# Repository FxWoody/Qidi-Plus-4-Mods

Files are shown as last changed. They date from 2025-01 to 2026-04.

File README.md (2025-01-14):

# Qidi Plus 4
Mods, Prints and config files for the QP4 of my own machine
The config files here are working 100% on my printer, i cannot garantee, nor be responsible, if the setups in here will be fully working on yours if you have not install or modified them.
Every modifications have been taken from Qidi-Community page as for what was available.
Some of my OWN mods are minor readjustments i made to my printer according to the reference of Community.

PLEASE make sure you have fully made a back-up of your system before using these config :)

Enjoy !!!

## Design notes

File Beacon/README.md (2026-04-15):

# **BEACON RevH "Normal" INSTALL ON QIDI PLUS 4**

## ***---IMPORTANT---***
## These MACRO SCRIPT FILES are from my own QIDI PLUS 4 modifications in order to make Beacon3D probe to work and is mainly, a copy of Stew675's AMAZING script.
##

### :+1:Please be advise that these modifications are not PART of QIDI's own Klipper and therefor, i will not take any responsability for any issues that could prevail from using these scripts. I have also made many more adjusments that have been taken from the community page and that are fully integrated into these, thanks to crew of Discord, and that you can read here : [Qidi-Community](https://github.com/qidi-community/Plus4-Wiki/tree/main). :+1:

#### *** This install is fully working and should be followed very carefully :wink:*** ####

## Install the PROBE on the toolhead
Download my files from Printables:
https://www.printables.com/model/1165232-qidi-plus-4-beacon-cooling-fan

Or you can use Stew's setup :
https://www.printables.com/model/1170120-beacon3d-mount-for-qidi-plus4

> ***NOTE that by using my Beacon Module installation, the probe will be on the right side on the tool head and requires to replace the cooling DUCT !!! I have added the STL for this puposes and my fan/duct system is more efficient than the original one***
> blower-beacon

Remove old probe, fan housing, and replace with new printed one.
**I will make some DEMO pic soon**

## Let's get ready in the KLIPPER :

In order to install Beacon, you will need to SSH into MKS folder with Mobaxterm 

Follow this to SSH how to: [SSH Communtity](https://github.com/qidi-community/Plus4-Wiki/blob/main/content/ssh-access/README.md).

Once in SSH, you will need to install the Beacon script:
> ***Install Beacon Module***
#### Clone beacon_klipper from git and run the install script:

```
cd ~
git clone https://github.com/beacon3d/beacon_klipper.git
./beacon_klipper/install.sh
```

Now that **BEACON** is installed, we need to replace the ***PROBE.PY*** inside the **KLIPPER**.
Navigate to the ***/home/mks/klipper/klippy/extras/*** like so : 

https://github.com/user-attachments/assets/80a6965c-9cf2-4efb-97a6-fbfab288c99c
#### From here, we have two choice in order to replace the Python File ####
You can simply **DRAG & DROP** the file you recovered earlier from your PC, or double click the PROBE.PY, this will open the **MobaTextEditor** ,select ALL, and paste the PROBE.PY file over-write it. 
> [!NOTE]
> Saving will bring you to a contextual menu for you to agree to **SAVE**.
After this, we are done in SSH mode.

## Copy/Paste of the .cfg files
> [!IMPORTANT]
***First -***, in your QP4 configuration, locate the **printer.cfg** and **gcode_macro.cfg**, rename those as ***park-printer.cfg*** and ***park-gcode_macro.cfg*** so that you can revert to it later (saving it on your PC with notepad or your favorite editor, *Mobaxterm* as is own that you can use, is even better as a backup)
>
> ***NOTE -*** My config files have been tuned for my OWN printer and might need to be readjusted to your printer setup. I have removed the mods that are not necessary, but, i would HIGLY suggest that you install SHAKETUNE :
> https://github.com/qidi-community/ShakeTune-For-Plus4

Open the ***printer.cfg & gcode_macro.cfg*** from this repository and copy them into each of your ***Configuration Files*** by creating each new files like so :

***NOTE THAT I OMIT THE ".CFG" AFTER WRITING "PRINTER" ...PLEASE REMEMBER TO ADD IT WHEN CREATING YOUR FILE*** 

https://github.com/user-attachments/assets/59b034cf-4111-4476-8d64-ce53f5c2da31
> [!IMPORTANT]
Then, simply COPY / PASTE each macro into their own folder .... **Save & Restart** will be ask at each file closer. I have also include KAMP settings if you want to adjust it to your taste (but it is set for quick purging  **NOTE:** ***LINE_PURGE need to be added to your printer setings Machine_start-gcode***)
>
> Now that Beacon is install, we are ready to do the **calibrations**.
>
## Calibration of your new Beacon
With all the above changes in place (and the firmware restarted) your Beacon can now be easily calibrated with the following typed into the Gcode Console:
```
G32
G29
G31
SAVE_CONFIG
```
This will set the Plus4 to generate a default bed mesh (G32), then do a full calibration home and bed mesh (G29), and then finally put the Plus4 back into Kamp mode meshing ready for the next print (G31). The whole lot gets saved afterwards (SAVE_CONFIG)

>
> Please refer to the "Beacon Instal Page" in the link below for proper calibration and better understanding of the probe.

# Links to External

SSH software: [MobaXterm](https://mobaxterm.mobatek.net/download.html).

Beacon Install page: [Beacon](https://docs.beacon3d.com/quickstart/).

Beacon Probe RevH: [Beacon Probe RevH Model : Normal](https://beacon3d.com/product/beacon-h/).

Qidi Community Work : [Qidi-Community Github](https://github.com/qidi-community/Plus4-Wiki/tree/main).

Facebook QidiTech : [QidiTech Officia](https://www.facebook.com/groups/qiditechofficialusers).



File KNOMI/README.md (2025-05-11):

# **KNOMI V1 INSTALL ON QIDI PLUS 4**

## ***---IMPORTANT---***
## These MACRO SCRIPT FILES are from my own QIDI PLUS 4 modifications in order to make KNOMI to work.
##

### :+1:Please be advise that these modifications are not PART of QIDI's own Klipper and therefor, i will not take any responsability for any issues that could prevail from using these scripts. I have also made many more adjusments that have been taken from the community page and that are fully integrated into these, thanks to crew of Discord, and that you can read here : [Qidi-Community](https://github.com/qidi-community/Plus4-Wiki/tree/main). :+1:

#### *** This install is fully working and should be followed very carefully. Do not forget that this MOD is based on the BEACON mod and is fully implemented for it but should FIT without it too except for some differences on the cover built :wink:*** ####

## Install the KNOMI in the toolhead cover
Download my files from Printables:

Knomi Cover: [Fxwoody Printables](https://www.printables.com/model/1214824-qidi-plus-4-knomi-cover)

## Let's get ready in the CONFIGS :

In order to have KNOMI to hook with our printer, we need to UPDATE the firmware first.

Follow the instructions from BTT page

BTT Knomi: https://bttwiki.com/KNOMI.html

## Add Knomi.cfg to your repo

>In printer.cfg, add the macro link
> `[include KNOMI.cfg]`

>[!IMPORTANT]
>#### Use the PB4 connector to power your Knomi

> Find :
```ruby
[heater_fan hotend_fan2]
pin:PB4
max_power: 1.0
shutdown_speed:1.0
kick_start_time: 0.5
heater: extruder
heater_temp: 50.0
fan_speed: 1.0
off_below: 0
```

and replace with:

```ruby
[output_pin knomi]
pin: PB4
value: 1
shutdown_value: 1
```
pcb

## Create your KNOMI.cfg file and paste this in it
```ruby
[gcode_macro _KNOMI_STATUS]
variable_homing: False
variable_probing: False
variable_qgling: False
variable_heating_nozzle: False
variable_heating_bed: False
gcode:

[gcode_macro M109]
rename_existing: M109.1
gcode:
  SET_GCODE_VARIABLE MACRO=_KNOMI_STATUS VARIABLE=heating_nozzle VALUE=True
  M109.1 {rawparams}
  SET_GCODE_VARIABLE MACRO=_KNOMI_STATUS VARIABLE=heating_nozzle VALUE=False

[gcode_macro M190]
rename_existing: M190.1
gcode:
  SET_GCODE_VARIABLE MACRO=_KNOMI_STATUS VARIABLE=heating_bed VALUE=True
  M190.1 {rawparams}
  SET_GCODE_VARIABLE MACRO=_KNOMI_STATUS VARIABLE=heating_bed VALUE=False

[gcode_macro G28]
rename_existing: G28.1
gcode:
  SET_GCODE_VARIABLE MACRO=_KNOMI_STATUS VARIABLE=homing VALUE=True
  G28.1 {rawparams}
  SET_GCODE_VARIABLE MACRO=_KNOMI_STATUS VARIABLE=homing VALUE=False

[gcode_macro _BED_MESH_CALIBRATE]
rename_existing: BTT_BED_MESH_CALIBRATE
gcode:
  SET_GCODE_VARIABLE MACRO=_KNOMI_STATUS VARIABLE=qgling VALUE=True
  BTT_BED_MESH_CALIBRATE {rawparams}
  SET_GCODE_VARIABLE MACRO=_KNOMI_STATUS VARIABLE=qgling VALUE=False

[gcode_macro Z_TILT_ADJUST]
rename_existing: BTT_Z_TILT_ADJUST
gcode:
 SET_GCODE_VARIABLE MACRO=_KNOMI_STATUS VARIABLE=probing VALUE=True
 BTT_Z_TILT_ADJUST
 SET_GCODE_VARIABLE MACRO=_KNOMI_STATUS VARIABLE=probing VALUE=False
```

# Links to External

VS Code software: [Visual Studio Code](https://code.visualstudio.com/).

KNOMI V1: [KNOMI](https://bttwiki.com/KNOMI.html).

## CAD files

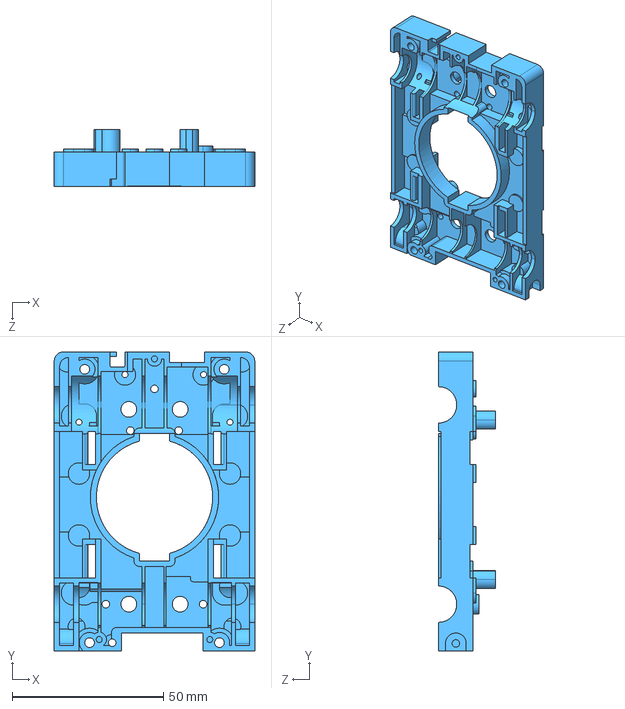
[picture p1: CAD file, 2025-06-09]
QidiP4/plus4底座后.STEP
66.4 x 99.0 x 18.8 mm

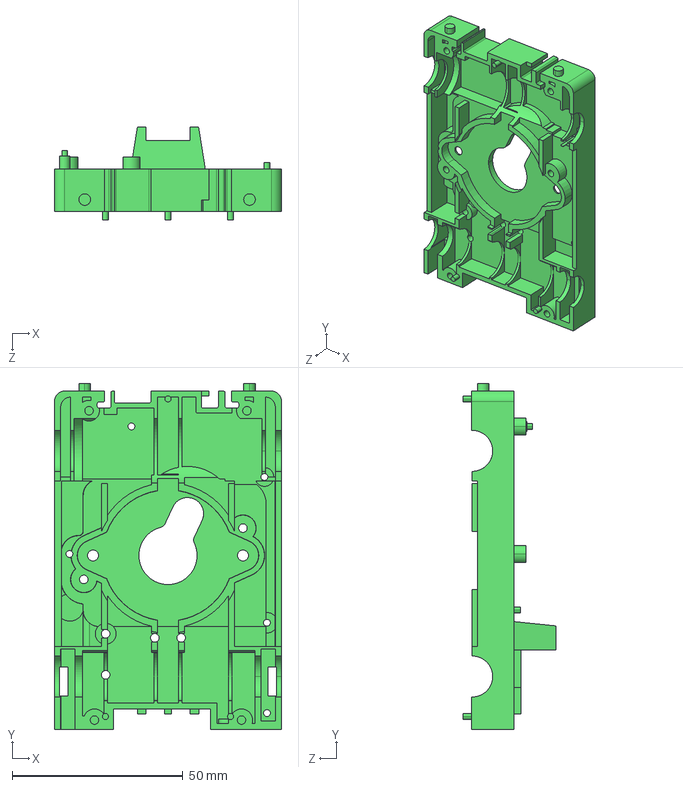
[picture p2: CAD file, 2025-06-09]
QidiP4/plus4底座前.STEP
66.4 x 101.2 x 27.2 mm

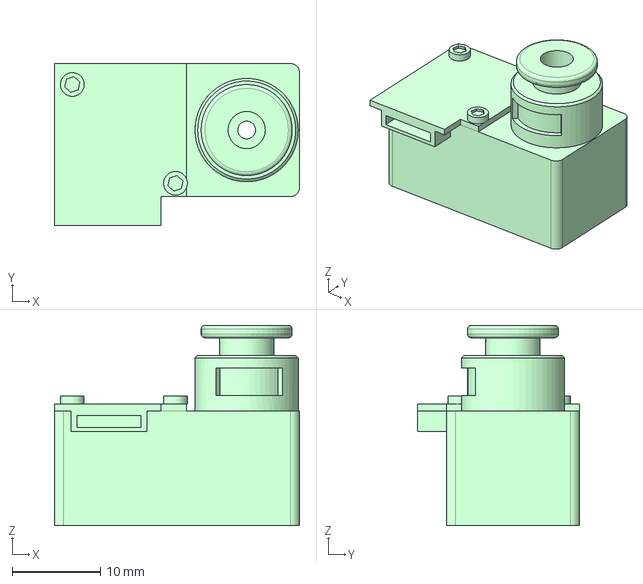
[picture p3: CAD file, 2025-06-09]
QidiP4/filament-sensor.stp
27.8 x 18.4 x 22.7 mm

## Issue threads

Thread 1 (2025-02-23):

cartographer compatibility

naytmare1, 2025-02-23:
Would this mount also work with cartographer v3 standard?

naytmare1, 2025-02-23:
i really like the design, I tried printing this with ASA but its always to brittle I dont know if my ASA has a problem hopefully I can think of a different orientation so

Closed 2025-02-23.

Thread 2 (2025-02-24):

Which Beacon H variation?

JohnnyPicnic, 2025-02-24:
Hi, could you include in your documentation with variation you are using or if it matters?
Normal or Low Profile.
Thanks!

FxWoody, 2025-02-24:
I add it but if you look at the links at the bottom i did specified it 😁👍

JohnnyPicnic, 2025-02-24:
Yup I see it now 😆 thanks.

FxWoody, 2025-02-24:
I will redo the whole install this week as i am using a mix of Stew675 and my scripts instead. Much better and i will upload both files here to simply copy-paste them with every modifications done and adjusted inside your machines.

Closed 2025-02-24.

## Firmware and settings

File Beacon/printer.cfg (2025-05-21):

# QIDI Plus4 V1.0.0

[include plr.cfg]
[include gcode_macro.cfg]
[include time_update.cfg]

# Plugins
[include timelapse.cfg]
[include KAMP_Settings.cfg]
#[include KNOMI.cfg]

[mcu]
serial: /dev/ttyS2
restart_method: command
baud:500000

[mcu U_1]
serial: /dev/ttyS0
restart_method: command
baud:500000

[temperature_sensor GD32]
sensor_type: temperature_mcu
sensor_mcu: mcu

[temperature_sensor mainboard_stm32]
sensor_type: temperature_mcu
sensor_mcu: U_1

[temperature_sensor mainboard_rockchip]
sensor_type: temperature_host

[respond]
default_type: echo

[save_variables] 
filename =/home/mks/printer_data/config/saved_variables.cfg

[resonance_tester]
accel_per_hz: 150
max_smoothing:0.5

[duplicate_pin_override]
pins:

[bed_screws]
screw1:15,15
screw1_name: Front left
screw2: 290,15
screw2_name: Front right
screw3: 285,290
screw3_name: Last right
screw4: 28,290

[screws_tilt_adjust]
screw1:5,20
screw1_name: Front left
screw2: 260,20
screw2_name: Front right
screw3: 260,280
screw3_name: Back right
screw4: 5,280
screw4_name: Back left
screw_thread: CW-M4

[hall_filament_width_sensor]
adc1: PA2
adc2: PA3
cal_dia1: 1.50
cal_dia2: 2.0
raw_dia1: 14397
raw_dia2: 15058
default_nominal_filament_diameter: 1.75
max_difference: 0
measurement_delay: 50
enable: false
measurement_interval: 10
logging: False
min_diameter: 0.3
use_current_dia_while_delay: False
pause_on_runout:True
runout_gcode:
            RESET_FILAMENT_WIDTH_SENSOR
            M118 Filament run out
event_delay: 3.0
pause_delay: 0.5

[extruder]
step_pin:PB9
dir_pin:PB8
enable_pin:!PC15
rotation_distance: 54.130 #53.7 22.6789511 Bondtech 5mm Drive Gears
gear_ratio: 1517:170
microsteps: 64 #16
full_steps_per_rotation: 200 #200 for 1.8 degree, 400 for 0.9 degree
nozzle_diameter: 0.400
filament_diameter: 1.75
min_temp: 0
max_temp: 380
min_extrude_temp: 175
smooth_time: 0.000001
heater_pin:PB3
sensor_type:MAX6675
sensor_pin:PB12
spi_speed: 100000
spi_software_sclk_pin:PB13
spi_software_mosi_pin:PA11
spi_software_miso_pin:PB14
max_power: 1

#control : pid  
#pid_Kp=33.555
#pid_Ki=4.76
#pid_Kd=59.141

pressure_advance: 0.032
pressure_advance_smooth_time: 0.03
max_extrude_cross_section: 500
instantaneous_corner_velocity: 10.000
max_extrude_only_distance: 1000.0
max_extrude_only_velocity:5000
max_extrude_only_accel:5000
step_pulse_duration:0.000002

[tmc2209 extruder]
uart_pin:PC13
interpolate: False #True
run_current: 0.8 #0.714
stealthchop_threshold: 0

[adxl345]
cs_pin:PA4
spi_software_sclk_pin:PA5
spi_software_mosi_pin:PA7
spi_software_miso_pin:PA6
axes_map: -x, z, -y

[printer]
kinematics:corexy
max_velocity: 600
max_accel: 20000
max_accel_to_decel: 10000
max_z_velocity: 20
max_z_accel: 500
square_corner_velocity: 5

[stepper_x]
step_pin:U_1:PB4
dir_pin:!U_1:PB3
enable_pin:!U_1:PB5
microsteps:32
rotation_distance: 38.86
full_steps_per_rotation:200 # set to 400 for 0.9 degree stepper
endstop_pin:tmc2240_stepper_x:virtual_endstop
position_min: -1.5
position_endstop: -1.5
position_max:307
homing_speed:75 #50
homing_retract_dist:0
homing_positive_dir:false
step_pulse_duration:0.0000001

[stepper_y]
step_pin:U_1:PC14
dir_pin:!U_1:PC13
enable_pin:!U_1:PC15
microsteps: 32
rotation_distance: 38.86
full_steps_per_rotation:200 # set to 400 for 0.9 degree stepper
endstop_pin:tmc2240_stepper_y:virtual_endstop
position_min: -2
position_endstop: -2
position_max:325
homing_speed:75 #50
homing_retract_dist:0
homing_positive_dir:false
step_pulse_duration:0.0000001

[stepper_z]
step_pin:U_1:PB1
dir_pin:U_1:PB6
enable_pin:!U_1:PB0
microsteps:16 #128
rotation_distance: 4
full_steps_per_rotation: 200
endstop_pin:probe:z_virtual_endstop # U_1:PC3 for Z-max
endstop_pin_reverse:tmc2209_stepper_z:virtual_endstop
#position_endstop:1
position_endstop_reverse:285
position_max:285
position_min: -4
homing_speed: 15
homing_speed_reverse: 15#10
second_homing_speed: 35
homing_retract_dist: 0 #5.0
homing_positive_dir:false
homing_positive_dir_reverse:true
#step_pulse_duration:0.0000001

[stepper_z1]
step_pin:U_1:PC10
dir_pin:U_1:PA15
enable_pin:!U_1:PC11
microsteps:16 #128
rotation_distance: 4
full_steps_per_rotation: 200
endstop_pin_reverse:tmc2209_stepper_z1:virtual_endstop
#step_pulse_duration:0.0000001

[z_tilt]
z_positions:
    -17.5,152
    335.7,152

points:
    40,152
    260,152

speed: 200
horizontal_move_z: 15
retries: 2
retry_tolerance: 0.015

[tmc2240 stepper_y]
cs_pin:U_1:PB9
spi_software_sclk_pin:U_1:PA5
spi_software_mosi_pin:U_1:PA7
spi_software_miso_pin:U_1:PA6
spi_speed:200000
run_current: 1.15
#hold_current: 0.5
interpolate: False #true
stealthchop_threshold:0
diag0_pin:!U_1:PC0
driver_SGT:1

[tmc2240 stepper_x]
cs_pin:U_1:PD2
spi_software_sclk_pin:U_1:PA5
spi_software_mosi_pin:U_1:PA7
spi_software_miso_pin:U_1:PA6
spi_speed:200000
run_current: 1.15
# hold_current: 0.5
interpolate:False #true
stealthchop_threshold:0
diag0_pin:!U_1:PB8
driver_SGT:1

[tmc2209 stepper_z]
uart_pin:U_1: PB7
run_current: 1.15
# hold_current: 0.17
interpolate: False #True
stealthchop_threshold: 999999
diag_pin:^U_1:PA13
driver_SGTHRS:100

[tmc2209 stepper_z1]
uart_pin:U_1: PC5
run_current: 1.15
# hold_current: 0.17
interpolate: False #True
stealthchop_threshold: 999999
diag_pin:^U_1:PC12
driver_SGTHRS:100

[heater_bed]
heater_pin: U_1:PB10
sensor_type:NTC 100K MGB18-104F39050L32
sensor_pin:U_1: PA0
max_power: 1.0
control = pid
pid_Kp=63.418 
pid_Ki=1.342 
pid_Kd=749.125
pwm_cycle_time:0.001
min_temp: -60
max_temp: 125

[temperature_sensor chamber_probe]
sensor_type:NTC 100K MGB18-104F39050L32
sensor_pin:U_1:PA1

[heater_generic chamber]
heater_pin:U_1:PC8
max_power:0.6 #0.4
pwm_cycle_time:0.02088            # Reduced to 0.02088 seconds to reduce flicker (within 0.3 limit)
control = pid
pid_Kp=45
pid_Ki=0.1
pid_Kd=5000
#control = pid
#pid_Kp=63.418 
#pid_Ki=1.342 
#pid_Kd=749.125
min_temp:-100
max_temp:80#70
target_min_temp:40
#target_max_temp:65
sensor_type: temperature_combined
sensor_list: temperature_sensor GD32, temperature_sensor chamber_probe, temperature_sensor GD32, temperature_sensor GD32
combination_method: mean
maximum_deviation: 70
heat_with_heater_bed:True
heat_with_heater_bed_tem_add:25

[verify_heater chamber]
max_error: 300
check_gain_time:1200 #480
hysteresis: 5
heating_gain: 1

[temperature_sensor Chamber_Thermal_Protection_Sensor]
sensor_type:NTC 100K MGB18-104F39050L32
sensor_pin:U_1:PC2
min_temp:-100
max_temp:130

[verify_heater extruder]
max_error: 120
check_gain_time:20
hysteresis: 5
heating_gain: 1

[verify_heater heater_bed]
max_error: 200
check_gain_time:360
hysteresis: 10
heating_gain: 1

[fan_generic exhaust_fan]
pin: U_1:PA8
shutdown_speed: 0.0
cycle_time: 0.0100
hardware_pwm: false
kick_start_time: 0.100
off_below: 0.0

[fan_generic chamber_circulation_fan]
pin: U_1:PC9
shutdown_speed: 0.0
cycle_time: 0.0100
hardware_pwm: false
kick_start_time: 0.100
off_below: 0.0

[chamber_fan chamber_fan]
pin:U_1:PA4
max_power: 1.0
shutdown_speed: 1.0
kick_start_time: 0.5
heater:chamber
fan_speed: 1.0
off_below: 0
idle_timeout:60
idle_speed:1.0

[output_pin knomi]
pin: PB4
value: 1
shutdown_value: 1

[heater_fan hotend_fan]
pin:PB5
max_power: 1.0
shutdown_speed:1.0
kick_start_time: 0.5
heater: extruder
heater_temp: 50.0
fan_speed: 1.0
off_below: 0

[fan_generic Raiser_Cooler]
pin:PB10
max_power: 1.0
shutdown_speed:0.0 #1.0
cycle_time: 0.0100
hardware_pwm: false
kick_start_time: 1.0
off_below: 0

[fan_generic cooling_fan]
pin:PA8
max_power: 1.0
shutdown_speed:0
cycle_time: 0.010
hardware_pwm: False
kick_start_time: 0.100
off_below: 0.0
tachometer_pin:PA9
tachometer_ppr: 2
tachometer_poll_interval: 0.0015

[controller_fan board_fan]
pin:U_1:PB2

[temperature_sensor mainboard_stm32]
sensor_type: temperature_mcu
sensor_mcu: U_1

[temperature_sensor mainboard_rockchip]
sensor_type: temperature_host

[temperature_fan adaptive_board_fan]
pin:U_1:PC4
max_power: 1.0
shutdown_speed: 1.0
cycle_time: 0.01
sensor_type: temperature_combined
sensor_list: temperature_sensor mainboard_stm32, temperature_sensor mainboard_rockchip
combination_method: max                                           # use the maximum reading of the sensors
maximum_deviation: 999.9                                          # we don't care about the difference in temperature
control: pid
pid_deriv_time: 2.0
pid_Kp: 5
pid_Ki: 2
pid_Kd: 5
target_temp: 45
min_speed: 0.8
max_speed: 1.0
min_temp: 0
max_temp: 100

[output_pin caselight]
pin: U_1:PC7
pwm: false
shutdown_value:1
value:1

[output_pin beeper]
pin:U_1: PA2
pwm: false
shutdown_value:0
value:0

[output_pin ctlyd]
pin:U_1: PA14
pwm: false
shutdown_value:0
value:0
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

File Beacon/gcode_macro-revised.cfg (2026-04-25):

# QIDI Plus4 V1.0.0

[gcode_macro _CG28]
gcode:
    {% if "xyz" not in printer.toolhead.homed_axes %}
        G28
    {% endif %}
    
[gcode_macro _APPLY_NOZZLE_OFFSET]
description: Determine the global nozzle offset and apply
variable_hotend_temp: 250               # Target hotend temp (typically set by PRINT_START)
variable_probe_temp_delta: 75           # We probe at this amount less than the hotend temp
variable_reference_position: 5.0        # A safe Z position at which we'll apply the offset change
variable_offset_correction: 0.07        # Static Offset Correction
gcode:
    # Set our local working variables.  We treat everything as floats for these calculations
    {% set reference_position = reference_position|float %}
    {% set offset_correction  = offset_correction|float %}

    # Determine the rest of our working variables
    {% set z_home_x = printer.configfile.settings.beacon.home_xy_position[0] %}
    {% set z_home_y = printer.configfile.settings.beacon.home_xy_position[1] %}
    {% set z_speed  = printer.configfile.settings['stepper_z'].homing_speed|float * 60 %}
    
    {% set target_position = (reference_position + offset_correction)|float %}

    # Report to the console what we've determined
    { action_respond_info("Applying Z offset adjustment for hotend temperature of %.1f°C" % hotend_temp|float) }
    { action_respond_info("  Offset Correction    = %.3f" % (offset_correction)|float) }
    { action_respond_info("  Reference Position   = %.1f" % (reference_position)|float) }
    { action_respond_info("  Target Position      = %.6f" % (target_position)|float) }

    SET_GCODE_OFFSET Z=0                            # Clear any pre-existing Gcode offsets
    G1 Z{target_position} F{z_speed}                # Move Z to determined target position
    G1 X{z_home_x} Y{z_home_y} F7200                # Move X/Y to Z homing position 
    M400                                            # Wait for prior gcode-commands to finish
    SET_KINEMATIC_POSITION Z={reference_position}   # Set target position to be the reference position
    G1 Z{reference_position} F600                   # Move Z to reference position.  Ideally the bed should not move
    M400

[gcode_macro _SETTLE_PRINT_BED]
gcode:
    G1 Z4 F600                              # Move to Z=4
    G91                                     # Enter relative positioning mode
    M400                                    # Wait for all prior commands to finish
    {% for z in range(50) %}                # Loop 50 times
        G1 Z1 F5000                         # Move bed down by 1mm
        G1 Z-1 F5000                        # Move bed up by 1mm
    {% endfor %}
    G90                                     # Go back to absolute positioning mode
    M400                                    # Wait for all prior commands to finish
    G1 Z4 F600                              # Make sure Z=4mm before we leave the macro

[gcode_macro _FIND_Z_EQUALS_ZERO]
gcode:
    {% set hotend_temp = (printer["gcode_macro _APPLY_NOZZLE_OFFSET"].hotend_temp)|float %}
    {% set probe_temp_delta = (printer["gcode_macro _APPLY_NOZZLE_OFFSET"].probe_temp_delta)|float %}

    {% set z_home_temp = hotend_temp - probe_temp_delta %}
    {% set z_home_x = printer.configfile.settings.beacon.home_xy_position[0] %}
    {% set z_home_y = printer.configfile.settings.beacon.home_xy_position[1] %}

    M104 S{z_home_temp}                     # Commence nozzle warmup for z homing        
    BED_MESH_CLEAR                          # Clear out any existing bed meshing context
    SET_KINEMATIC_POSITION Z=0              # Force firmware to believe Z is homed at 0
    G1 Z3 F600                              # Move bed away from the nozzle by 3mm from where it was
    SET_KINEMATIC_POSITION CLEAR=XYZ        # Ensure all kinematic repositionings are cleared
    SET_GCODE_OFFSET Z=0                    # Comnpletely reset all prior notions of Z offset
    G28 X Y                                 # Home X and Y Axes
    {% if (printer.configfile.settings['beacon model default'] is defined) %}
        G28 Z METHOD=proximity              # Do a rapid proximity based Z home if possible
    {% else %}
        M109 S{z_home_temp}                 # Wait for nozzle to fully heat up
        G28 Z METHOD=CONTACT CALIBRATE=0    # Home Z axis without calibration
    {% endif %}
    _SETTLE_PRINT_BED                        # Try to settle the build plate
    M109 S{z_home_temp}                     # Wait for nozzle to fully reach Z probing temperature
    G28 Z METHOD=CONTACT CALIBRATE=1        # Home Z axis, and calibrate beacon                                     
    Z_TILT_ADJUST                           # Ensure bed is level
    G1 X{z_home_x} Y{z_home_y} F7200        # Move to Z home position
    G4 P15000                               # Heatsoak hotend for 15s more
    G28 Z METHOD=CONTACT CALIBRATE=1        # Establish Z=0
    G1 Z3 F600                              # Move bed away from the nozzle by 3mm from where it was
    _APPLY_NOZZLE_OFFSET

[gcode_macro APPLY_FILAMENT_OFFSET]
description: Apply a Z offset adjustment for a specific filament
gcode:
    {% set filament_z = params.Z|default(0)|float %}
    { action_respond_info("Setting Filament Offset to %.3fmm" % (filament_z)) }
    SET_GCODE_OFFSET Z_ADJUST={filament_z}
    
# All the following zoffset calls only exist to keep Qidi's xindi happy
[gcode_macro zoffset]
description: Apply baseline Z offset which is always zero for Beacon Contact
gcode:
    SET_GCODE_OFFSET Z=0                    # Apply a zero gcode_offset

# Development test
[gcode_macro test_zoffset]
description: Debugging test to compare the probe contact and proximity Z Offset values
gcode:
    G28 X Y
    get_zoffset
    M400
    BEACON_OFFSET_COMPARE
    G4 P5000
    G1 Z10 F600

[gcode_macro get_zoffset]
description: Homes nozzle against build plate and applies global z offset
gcode:
    _FIND_Z_EQUALS_ZERO

[gcode_macro save_zoffset]
description: Use APPLY_FILAMENT_OFFSET instead
gcode:
    { action_respond_info("Use APPLY_FILAMENT_OFFSET instead") }

[gcode_macro set_zoffset]
description: Apply baseline Z offset which is always zero for Beacon Contact      
gcode: 
    SET_GCODE_OFFSET Z=0                    # Apply a zero gcode_offset

# Specialized for power lose recovery
[gcode_macro CLEAR_NOZZLE_PLR]
gcode:
    {% set hotendtemp = params.HOTEND|default(250)|int %}
    {% if (printer.gcode_move.position.z ) < 35 %}
        G1 Z35 F900
    {% else %}
        G91
        G1 Z{5} F900 
        G90
    {% endif %}
    G1 X56 F12000
    G1 Y310 F12000
    G1 Y324 F600
    G1 X95 F600
    M400

    M106 S0
    M109 S{hotendtemp}

    G92 E0
    G1 E5 F50
    G92 E0
    G1 E80 F200
    G92 E0
    G1 E-2 F200
    G4 P300

    M106 S255
    G1 Y316 F30000
    G1 Y320 F3000
    G1 Y316 F30000
    G1 Y320 F3000
    G1 Y316 F30000
    G1 Y320 F3000
    G1 Y316 F12000
    G1 Y312 F600

[gcode_macro CLEAR_NOZZLE]
gcode:
    {% set hotendtemp = params.HOTEND|default(250)|int %}
    {% if (printer.gcode_move.position.z ) < 35 %}
        G1 Z35 F900
    {% else %}
        G91
        G1 Z{5} F900 
        G90
    {% endif %}
    G1 X56 F12000
    G1 Y310 F12000
    G1 Y324 F600
    G1 X95 F600
    M400
    M109 S{hotendtemp}
    G92 E0
    G1 E5 F50
    G92 E0
    G1 E80 F200
    G92 E0
    G1 E-2 F200

    M106 S255
    G4 P5000
    M104 S140
    G1 Y318 F9000
    G1 Y322 F600
    G1 Y318 F9000
    G1 Y322 F600
    G1 Y308 F30000
    G1 Y324 F600

    G1 X124 E-1 F1000 

    TEMPERATURE_WAIT SENSOR=extruder MAXIMUM={170}

    G1 X133 F200
    G1 Y321 F200
    G2 I0.5 J0.5 F600
    G2 I0.5 J0.5 F600
    G2 I0.5 J0.5 F600

    G1 Y319 F150
    G1 X132 
    G1 Y324
    G1 X131 
    G1 Y319
    G1 X130
    G1 Y324
    G1 X129
    G1 Y319

    G1 X113 F200
    G1 Y320
    G1 X125
    G1 X113
    G1 X125
    G2 I0.5 J0.5 F200
    G2 I0.5 J0.5 F200
    G2 I0.5 J0.5 F200    

    G1 Y300 F600
    G1 X95 F12000
    G1 Y314 F9000
    G1 Y324 F600

    G1 X58 F12000
    G1 X78 F12000
    G1 Y324
    G1 X58 F12000
    G1 X78 F12000
    G1 Y323.5
    G1 X58 F12000
    G1 X78 F12000
    G1 Y323
    G1 X58 F12000
    G1 X78 F12000
    G1 Y322.5
    G1 X58 F12000
    G1 X78 F12000
    G1 Y322
    G1 X58 F12000
    G1 X75 F12000
    G1 Y321.5
    G2 I0.8 J0.8 F600
    G2 I0.8 J0.8 F600
    G2 I0.8 J0.8 F600

    G1 Y324 F600

    M106 S0

    G1 X95 F12000
    G1 Y316 F9000
    G1 Y312 F600

    M400
    M118 Nozzle cleared
    G1 Y10 F12000
    G1 X10 F12000
    TEMPERATURE_WAIT SENSOR=extruder MAXIMUM={150}
    M107
    M106 P2 S0
    M400
    M118 Nozzle cooled

[gcode_macro MOVE_TO_TRASH]
gcode:
    _CG28
    M204 S10000
    {% if (printer.gcode_move.position.y) > 305 %}
        G1 X82.5 Y324 F6000
        G1 X95
    {% else %}
        G1 X82.5 F12000
        G1 Y310 F12000
        G1 Y324 F600
        G1 X95 F6000
    {% endif %}
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

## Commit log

2024-11-02 Create Klipper
2025-01-26 printer.cfg
    Beacon Probe modified script
    [printer.cfg]
2025-01-26 SSH file probe.py
    This file need to be pasted over in klipper/klippy/extras/probe.py
2025-12-16 Adjust KAMP settings for mesh and purge parameters
    [KAMP_Settings.cfg]
2026-04-15 Add Ko-fi button to README
2026-04-25 Add G-code macro configuration for QIDI Plus4
    This commit introduces a new G-code macro configuration for the QIDI Plus4 printer, including various macros for nozzle offset application, print bed settling, and filament loading/unloading. It also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
    [gcode_macro-revised.cfg]
